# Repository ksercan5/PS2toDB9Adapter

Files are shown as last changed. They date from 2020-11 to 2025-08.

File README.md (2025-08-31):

# PS2toDB9Adapter
Use your Playstation2 Dualshock with Retro Computers (Commodore, Amiga and Atari)

For this project I used Bill Porter's PS2X Arduino Library (http://www.billporter.info/2010/06/05/playstation-2-controller-arduino-library-v1-0/)

For detailed information, please visit (http://seco.gen.tr/2020/07/20/ps2-dualshock-to-c64-joystick-port-mod/)

Use mouse_and_joystick arduino source code to add mouse functionality to your adapter.
To use mouse function (For Amiga only) Press R2 or L2 on Dualshock and move right analog stick. Cross is Left and Square is for Right Mouse Button

For first batch of production (only commodore.gen.tr users), please use v1.1

Other productions use V2 file. (Or you can use the file with mouse support)

# UPDATE:

New double card for C64 will be used to connect two PS2 controllers. Only one Arduino Nano will be enough (Finally tested ok:)

Please download the firmware for double board.

PCBWAY Link: https://www.pcbway.com/project/shareproject/Playstation_PS2_Dualshock_to_DB9__DSUB_9__Adapter_for_Commodore__Amiga_and_Atari_Computers.html

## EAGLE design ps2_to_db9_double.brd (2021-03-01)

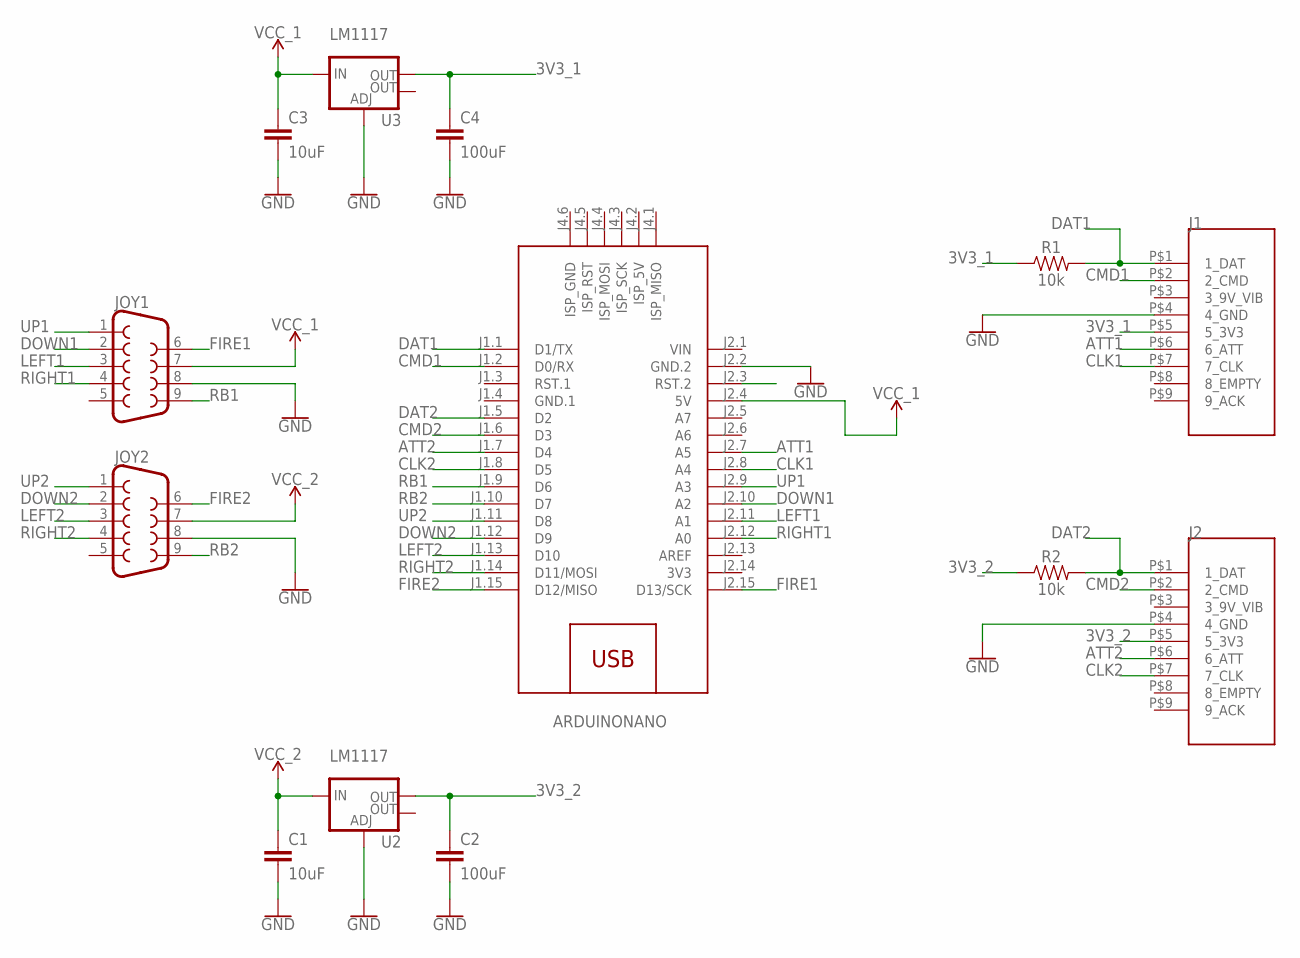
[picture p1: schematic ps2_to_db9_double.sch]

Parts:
ARDUINONANO: ARDUINO-NANO-3.0#ISP
C1, C3: 10uF; C025-025X050
C2, C4: 100uF; C025-025X050
J1, J2: PS2_DUALSHOCK_UP
JOY1, JOY2: DB9FEMALE; DB9
R1, R2: 10k; AXIAL-0.3
U2, U3: LM1117; SOT223

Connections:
3V3: ARDUINONANO.J2.14 (3V3)
3V3_1: C4.1, J1.P$5 (5_3V3), R1.P$1 (1), U3.2 (OUT)
3V3_2: C2.1, J2.P$5 (5_3V3), R2.P$1 (1), U2.2 (OUT)
ATT1: ARDUINONANO.J2.7 (A5), J1.P$6 (6_ATT)
ATT2: ARDUINONANO.J1.7 (D4), J2.P$6 (6_ATT)
CLK1: ARDUINONANO.J2.8 (A4), J1.P$7 (7_CLK)
CLK2: ARDUINONANO.J1.8 (D5), J2.P$7 (7_CLK)
CMD1: ARDUINONANO.J1.2 (D0/RX), J1.P$2 (2_CMD)
CMD2: ARDUINONANO.J1.6 (D3), J2.P$2 (2_CMD)
DAT1: ARDUINONANO.J1.1 (D1/TX), J1.P$1 (1_DAT), R1.P$2 (2)
DAT2: ARDUINONANO.J1.5 (D2), J2.P$1 (1_DAT), R2.P$2 (2)
DOWN1: ARDUINONANO.J2.10 (A2), JOY1.2
DOWN2: ARDUINONANO.J1.12 (D9), JOY2.2
FIRE1: ARDUINONANO.J2.15 (D13/SCK), JOY1.6
FIRE2: ARDUINONANO.J1.15 (D12/MISO), JOY2.6
GND: ARDUINONANO.J2.2 (GND.2), C1.2, C2.2, C3.2, C4.2, J1.P$4 (4_GND), J2.P$4 (4_GND), JOY1.8, JOY2.8, U2.1 (ADJ), U3.1 (ADJ)
GND.1: ARDUINONANO.J1.4 (GND.1)
LEFT1: ARDUINONANO.J2.11 (A1), JOY1.3
LEFT2: ARDUINONANO.J1.13 (D10), JOY2.3
RB1: ARDUINONANO.J1.9 (D6), JOY1.9
RB2: ARDUINONANO.J1.10 (D7), JOY2.9
RIGHT1: ARDUINONANO.J2.12 (A0), JOY1.4
RIGHT2: ARDUINONANO.J1.14 (D11/MOSI), JOY2.4
UP1: ARDUINONANO.J2.9 (A3), JOY1.1
UP2: ARDUINONANO.J1.11 (D8), JOY2.1
VCC_1: ARDUINONANO.J2.4 (5V), C3.1, JOY1.7, U3.3 (IN)
VCC_2: C1.1, JOY2.7, U2.3 (IN)
VIN: ARDUINONANO.J2.1 (VIN)

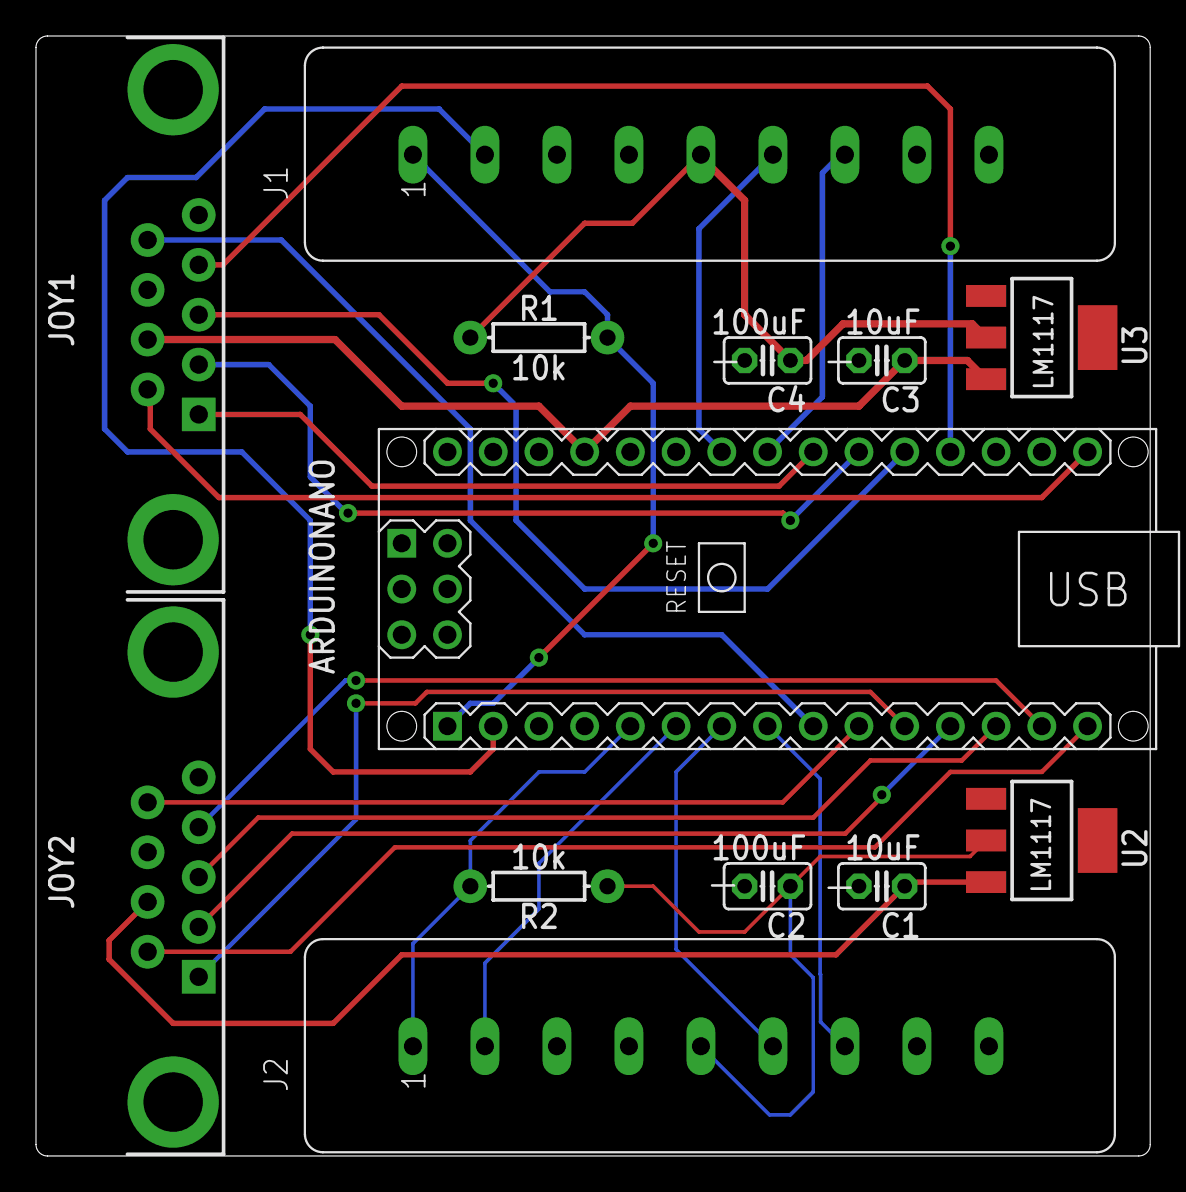
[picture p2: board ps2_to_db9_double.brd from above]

Board: 2 copper layers, 61.9 x 62.2 mm, 13 parts (0 on the bottom side), 25 nets.

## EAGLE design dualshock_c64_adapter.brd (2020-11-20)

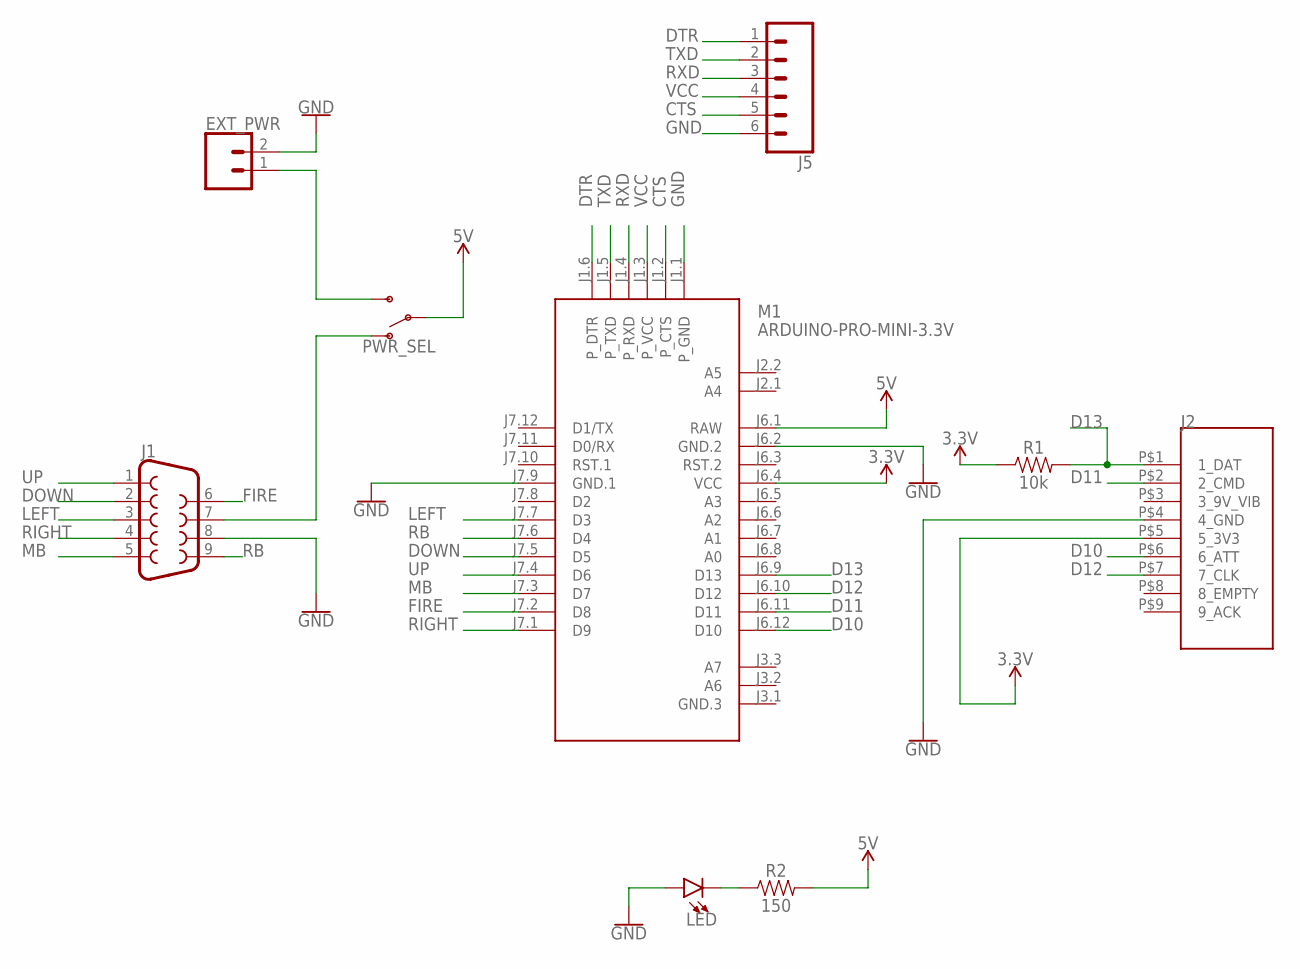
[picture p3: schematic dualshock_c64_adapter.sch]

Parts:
EXT_PWR: CONN_02; 1X02
J1: DB9FEMALE; DB9
J2: PS2_DUALSHOCK
J5: CONN_06NO_SILK_FEMALE_PTH; 1X06_NO_SILK
LED: LED5MM; LED_5MM
M1: ARDUINO-PRO-MINI-3.3V; ARDUINO-PRO-MINI
PWR_SEL: SWITCH-SPDT-PTH-11.6X4.0MM; SWITCH_SPDT_PTH_11.6X4.0MM
R1: 10k; AXIAL-0.3
R2: 150; AXIAL-0.3

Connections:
3.3V: J2.P$5 (5_3V3), M1.J6.4 (VCC), R1.P$1 (1)
5V: M1.J6.1 (RAW), PWR_SEL.2, R2.P$2 (2)
CTS: J5.5, M1.J1.2 (P_CTS)
D10: J2.P$6 (6_ATT), M1.J6.12 (D10)
D11: J2.P$2 (2_CMD), M1.J6.11 (D11)
D12: J2.P$7 (7_CLK), M1.J6.10 (D12)
D13: J2.P$1 (1_DAT), M1.J6.9 (D13), R1.P$2 (2)
DOWN: J1.2, M1.J7.5 (D5)
DTR: J5.1, M1.J1.6 (P_DTR)
FIRE: J1.6, M1.J7.2 (D8)
GND: EXT_PWR.2, J1.8, J2.P$4 (4_GND), J5.6, LED.A, M1.J1.1 (P_GND), M1.J6.2 (GND.2), M1.J7.9 (GND.1)
LEFT: J1.3, M1.J7.7 (D3)
MB: J1.5, M1.J7.3 (D7)
unnamed: LED.K (C), R2.P$1 (1)
unnamed: J1.7, PWR_SEL.1 (O)
unnamed: EXT_PWR.1, PWR_SEL.3 (S)
RB: J1.9, M1.J7.6 (D4)
RIGHT: J1.4, M1.J7.1 (D9)
RXD: J5.3, M1.J1.4 (P_RXD)
TXD: J5.2, M1.J1.5 (P_TXD)
UP: J1.1, M1.J7.4 (D6)
VCC: J5.4, M1.J1.3 (P_VCC)

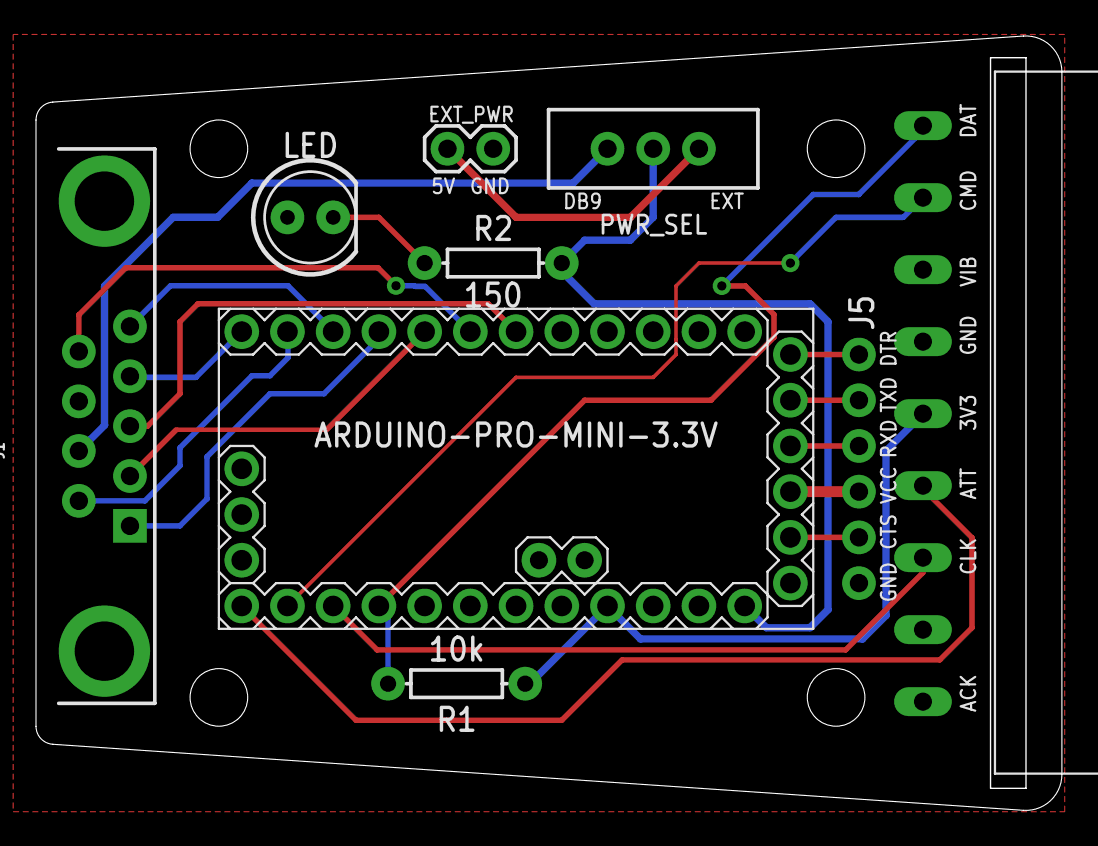
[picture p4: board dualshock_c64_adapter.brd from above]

Board: 2 copper layers, 57.0 x 43.0 mm, 9 parts (0 on the bottom side), 22 nets.

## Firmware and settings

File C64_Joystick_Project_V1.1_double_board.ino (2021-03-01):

// Version Update
// 1.0 Based on Code 2.1 for single adapter
// 27.02.2021
//
// Double Board for C64 with Arduino Nano
// by Sercan Kocabaş


#include <PS2X_lib.h>  //for v1.6

/******************************************************************
 * set pins connected to PS2 controller:
 *   - 1e column: original 
 *   - 2e colmun: Stef?
 * replace pin numbers by the ones you use
 ******************************************************************/
#define PS2_DAT_2        2  //14    
#define PS2_CMD_2        3  //15
#define PS2_SEL_2        4  //16
#define PS2_CLK_2        5  //17

#define C64_UP_2         8
#define C64_DOWN_2       9
#define C64_LEFT_2       10
#define C64_RIGHT_2      11
#define C64_FIRE_2       12

#define PS2_DAT_1        1  //14    
#define PS2_CMD_1        0  //15
#define PS2_SEL_1        A5  //16
#define PS2_CLK_1        A4  //17

#define C64_UP_1         A3
#define C64_DOWN_1       A2
#define C64_LEFT_1       A1
#define C64_RIGHT_1      A0
#define C64_FIRE_1       13

/******************************************************************
 * select modes of PS2 controller:
 *   - pressures = analog reading of push-butttons 
 *   - rumble    = motor rumbling
 * uncomment 1 of the lines for each mode selection
 ******************************************************************/
//#define pressures   true
#define pressures   false
//#define rumble      true
#define rumble      false

PS2X ps2x_1; // create PS2 Controller Class for Joy1
PS2X ps2x_2; // create PS2 Controller Class for Joy2


//right now, the library does NOT support hot pluggable controllers, meaning 
//you must always either restart your Arduino after you connect the controller, 
//or call config_gamepad(pins) again after connecting the controller.

byte error_1 = 0;
byte vibrate_1 = 0;

byte error_2 = 0;
byte vibrate_2 = 0;

void setup(){


  pinMode(A6, INPUT);
  pinMode(A7, INPUT);
  pinMode(C64_FIRE_1, INPUT);
  pinMode(C64_UP_1, INPUT);
  pinMode(C64_DOWN_1, INPUT);
  pinMode(C64_RIGHT_1, INPUT);
  pinMode(C64_LEFT_1, INPUT);


  pinMode(C64_FIRE_2, INPUT);
  pinMode(C64_UP_2, INPUT);
  pinMode(C64_DOWN_2, INPUT);
  pinMode(C64_RIGHT_2, INPUT);
  pinMode(C64_LEFT_2, INPUT);
   
  
  
  //Serial.begin(57600); //Enable this to enable serial communication for troubleshooting, in this case JOY1 will not be available. 
  
  delay(300);  //added delay to give wireless ps2 module some time to startup, before configuring it
   
  //CHANGES for v1.6 HERE!!! **************PAY ATTENTION*************

  Serial.println("Dualshock2 to DB9 (Commodore 64 --- Double Board ---) Adapter Software Ver 1.0");
  
  //setup pins and settings: GamePad(clock, command, attention, data, Pressures?, Rumble?) check for error
  error_1 = ps2x_1.config_gamepad(PS2_CLK_1, PS2_CMD_1, PS2_SEL_1, PS2_DAT_1, pressures, rumble);
  
//  if(error_1 == 0){
//    Serial.print("Found Controller 1, configured successful ");
//    Serial.print("pressures = ");
//	if (pressures)
//	  Serial.println("true ");
//	else
//	  Serial.println("false");
//	Serial.print("rumble = ");
//	if (rumble)
//	  Serial.println("true)");
//	else
//	  Serial.println("false");
//    Serial.println("Note: Go to https://github.com/ksercan5/PS2toDB9Adapter for updates and to report bugs.");
//  }  
//  else if(error_1 == 1)
//    Serial.println("No controller 1 found, check wiring, see readme.txt to enable debug. visit www.billporter.info for troubleshooting tips");
//   
//  else if(error_1 == 2)
//    Serial.println("Controller 1 found but not accepting commands. see readme.txt to enable debug. Visit www.billporter.info for troubleshooting tips");
//
//  else if(error_1 == 3)
//    Serial.println("Controller 1 refusing to enter Pressures mode, may not support it. ");
  
error_2 = ps2x_2.config_gamepad(PS2_CLK_2, PS2_CMD_2, PS2_SEL_2, PS2_DAT_2, pressures, rumble);
  
//  if(error_2 == 0){
//    Serial.print("Found Controller 2, configured successful ");
//    Serial.print("pressures = ");
//  if (pressures)
//    Serial.println("true ");
//  else
//    Serial.println("false");
//  Serial.print("rumble = ");
//  if (rumble)
//    Serial.println("true)");
//  else
//    Serial.println("false");
//    Serial.println("Note: Go to https://github.com/ksercan5/PS2toDB9Adapter for updates and to report bugs.");
//  }  
//  else if(error_2 == 1)
//    Serial.println("No controller 2 found, check wiring, see readme.txt to enable debug. visit www.billporter.info for troubleshooting tips");
//   
//  else if(error_2 == 2)
//    Serial.println("Controller 2 found but not accepting commands. see readme.txt to enable debug. Visit www.billporter.info for troubleshooting tips");
//
//  else if(error_2 == 3)
//    Serial.println("Controller 2 refusing to enter Pressures mode, may not support it. ");
//  
//
}


void check_joy1() {
  ps2x_1.read_gamepad(false, vibrate_1);
  // Analog left for Joy 1
    if(ps2x_1.Analog(PSS_LY) < 30 ){
      pinMode(C64_UP_1, OUTPUT);
      digitalWrite(C64_UP_1, LOW);
//      Serial.println("Analog up");
      }  else if ((!ps2x_1.Button(PSB_CIRCLE))&&(!ps2x_1.Button(PSB_PAD_UP)))
      pinMode(C64_UP_1, INPUT);
  
    if(ps2x_1.Analog(PSS_LY) > 225 ){
      pinMode(C64_DOWN_1, OUTPUT);
      digitalWrite(C64_DOWN_1, LOW);
//      Serial.println("Analog down");
      }  else if (!ps2x_1.Button(PSB_PAD_DOWN))
      pinMode(C64_DOWN_1, INPUT);
    
    if(ps2x_1.Analog(PSS_LX) < 20 ){
      pinMode(C64_LEFT_1, OUTPUT);
      digitalWrite(C64_LEFT_1, LOW);
//      Serial.println("Analog left");
      }  else if (!ps2x_1.Button(PSB_PAD_LEFT))
      pinMode(C64_LEFT_1, INPUT);
      
    if(ps2x_1.Analog(PSS_LX) > 235 ){
      pinMode(C64_RIGHT_1, OUTPUT);
      digitalWrite(C64_RIGHT_1, LOW);
//      Serial.println("Analog right");
      }  else if (!ps2x_1.Button(PSB_PAD_RIGHT))
      pinMode(C64_RIGHT_1, INPUT);

    if(ps2x_1.ButtonPressed(PSB_CIRCLE)) {              //will be TRUE if button was JUST pressed
//      Serial.println("Circle just pressed");
      pinMode(C64_UP_1, OUTPUT);
      digitalWrite(C64_UP_1, LOW);
    }  
     if(ps2x_1.ButtonPressed(PSB_CROSS)) {              //will be TRUE if button was JUST pressed
//      Serial.println("Cross just pressed");
      pinMode(C64_FIRE_1, OUTPUT);
      digitalWrite(C64_FIRE_1, LOW);
    }  
    if(ps2x_1.Button(PSB_TRIANGLE)) {              //Autofire code
//      Serial.println("Autofire pressed (Square)");
      pinMode(C64_FIRE_1, OUTPUT);
      digitalWrite(C64_FIRE_1, LOW);
      delay(50);
      pinMode(C64_FIRE_1, INPUT);
    }  
    
    if (ps2x_1.ButtonPressed(PSB_PAD_UP)) {
//      Serial.println("Pad Up pressed");
      pinMode(C64_UP_1, OUTPUT);
      digitalWrite(C64_UP_1, LOW);
    }    
    if (ps2x_1.ButtonPressed(PSB_PAD_DOWN)) {
//      Serial.println("Pad Down pressed");
      pinMode(C64_DOWN_1, OUTPUT);
      digitalWrite(C64_DOWN_1, LOW);
    }
      if (ps2x_1.ButtonPressed(PSB_PAD_LEFT)) {
//      Serial.println("Pad Left pressed");
      pinMode(C64_LEFT_1, OUTPUT);
      digitalWrite(C64_LEFT_1, LOW);
    }

    if (ps2x_1.ButtonPressed(PSB_PAD_RIGHT)) {
//      Serial.println("Pad Right pressed");
      pinMode(C64_RIGHT_1, OUTPUT);
      digitalWrite(C64_RIGHT_1, LOW);
    }   

    //Button released part Joy 1
 
    if(ps2x_1.ButtonReleased(PSB_CIRCLE)) {             //will be TRUE if button was JUST released
//      Serial.println("Circle just released");     
      pinMode(C64_UP_1, INPUT);
    }

    if(ps2x_1.ButtonReleased(PSB_CROSS)) {             //will be TRUE if button was JUST released
//      Serial.println("Cross just released");     
      pinMode(C64_FIRE_1, INPUT);
    }

    if(ps2x_1.ButtonReleased(PSB_TRIANGLE)) {             //will be TRUE if button was JUST released
//      Serial.println("Square just released");     
      pinMode(C64_FIRE_1, INPUT);
    }
    
    if (ps2x_1.ButtonReleased(PSB_PAD_UP)) {
//      Serial.println("Pad Up Released");
      pinMode(C64_UP_1, INPUT);
    }    

    if (ps2x_1.ButtonReleased(PSB_PAD_DOWN)) {
//      Serial.println("Pad Down Released");
      pinMode(C64_DOWN_1, INPUT);
    }    
    
    if (ps2x_1.ButtonReleased(PSB_PAD_LEFT)) {
//      Serial.println("Pad Left Released");
      pinMode(C64_LEFT_1, INPUT);
    }    
    
    if (ps2x_1.ButtonReleased(PSB_PAD_RIGHT)) {
//      Serial.println("Pad Rıght Released");
      pinMode(C64_RIGHT_1, INPUT);
    }  
}


void check_joy2() {
  ps2x_2.read_gamepad(false, vibrate_2);
// Analog left for Joy 2

    if(ps2x_2.Analog(PSS_LY) < 30 ){
      pinMode(C64_UP_2, OUTPUT);
      digitalWrite(C64_UP_2, LOW);
//      Serial.println("Analog up");
      }  else if ((!ps2x_2.Button(PSB_CIRCLE))&&(!ps2x_2.Button(PSB_PAD_UP)))
      pinMode(C64_UP_2, INPUT);
  
    if(ps2x_2.Analog(PSS_LY) > 225 ){
      pinMode(C64_DOWN_2, OUTPUT);
      digitalWrite(C64_DOWN_2, LOW);
 //     Serial.println("Analog down");
      }  else if (!ps2x_2.Button(PSB_PAD_DOWN))
      pinMode(C64_DOWN_2, INPUT);
    
    if(ps2x_2.Analog(PSS_LX) < 20 ){
      pinMode(C64_LEFT_2, OUTPUT);
      digitalWrite(C64_LEFT_2, LOW);
//      Serial.println("Analog left");
      }  else if (!ps2x_2.Button(PSB_PAD_LEFT))
      pinMode(C64_LEFT_2, INPUT);
      
    if(ps2x_2.Analog(PSS_LX) > 235 ){
      pinMode(C64_RIGHT_2, OUTPUT);
      digitalWrite(C64_RIGHT_2, LOW);
//      Serial.println("Analog right");
      }  else if (!ps2x_2.Button(PSB_PAD_RIGHT))
      pinMode(C64_RIGHT_2, INPUT);

    if(ps2x_2.ButtonPressed(PSB_CIRCLE)) {              //will be TRUE if button was JUST pressed
//      Serial.println("Circle just pressed");
      pinMode(C64_UP_2, OUTPUT);
      digitalWrite(C64_UP_2, LOW);
    }  
    if(ps2x_2.ButtonPressed(PSB_CROSS)) {              //will be TRUE if button was JUST pressed
//      Serial.println("Cross just pressed");
      pinMode(C64_FIRE_2, OUTPUT);
      digitalWrite(C64_FIRE_2, LOW);
    } 

    if(ps2x_2.Button(PSB_TRIANGLE)) {              //Autofire code
//      Serial.println("Autofire pressed (Square)");
      pinMode(C64_FIRE_2, OUTPUT);
      digitalWrite(C64_FIRE_2, LOW);
      delay(50);
      pinMode(C64_FIRE_2, INPUT);
    }  
     if (ps2x_2.ButtonPressed(PSB_PAD_UP)) {
//      Serial.println("Pad Up pressed");
      pinMode(C64_UP_2, OUTPUT);
      digitalWrite(C64_UP_2, LOW);
    }
    if (ps2x_2.ButtonPressed(PSB_PAD_DOWN)) {
//      Serial.println("Pad Down pressed");
      pinMode(C64_DOWN_2, OUTPUT);
      digitalWrite(C64_DOWN_2, LOW);
    }
    if (ps2x_2.ButtonPressed(PSB_PAD_LEFT)) {
//      Serial.println("Pad Left pressed");
      pinMode(C64_LEFT_2, OUTPUT);
      digitalWrite(C64_LEFT_2, LOW);
    }
    if (ps2x_2.ButtonPressed(PSB_PAD_RIGHT)) {
//      Serial.println("Pad Right pressed");
      pinMode(C64_RIGHT_2, OUTPUT);
      digitalWrite(C64_RIGHT_2, LOW);
    }   

     //Button released part Joy 2

    if(ps2x_2.ButtonReleased(PSB_CIRCLE)) {             //will be TRUE if button was JUST released
//      Serial.println("Circle just released");     
      pinMode(C64_UP_2, INPUT);
    }

    if(ps2x_2.ButtonReleased(PSB_CROSS)) {             //will be TRUE if button was JUST released
//      Serial.println("Cross just released");     
      pinMode(C64_FIRE_2, INPUT);
    }

    if(ps2x_2.ButtonReleased(PSB_TRIANGLE)) {             //will be TRUE if button was JUST released
//      Serial.println("Square just released");     
      pinMode(C64_FIRE_2, INPUT);
    }
    
    if (ps2x_2.ButtonReleased(PSB_PAD_UP)) {
//      Serial.println("Pad Up Released");
      pinMode(C64_UP_2, INPUT);
    }    

    if (ps2x_2.ButtonReleased(PSB_PAD_DOWN)) {
//      Serial.println("Pad Down Released");
      pinMode(C64_DOWN_2, INPUT);
    }    
    
    if (ps2x_2.ButtonReleased(PSB_PAD_LEFT)) {
//      Serial.println("Pad Left Released");
      pinMode(C64_LEFT_2, INPUT);
    }    
    
    if (ps2x_2.ButtonReleased(PSB_PAD_RIGHT)) {
//      Serial.println("Pad Rıght Released");
      pinMode(C64_RIGHT_2, INPUT);
    }   
}

void loop() {
  if (error_1 == 0) check_joy1();
  if (error_2 == 0) check_joy2();
  delay(25);   //Default 50
}

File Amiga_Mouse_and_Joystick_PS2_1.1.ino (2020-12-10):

#include <PS2X_lib.h>  //for v1.6

/*Data from PS2-Mouse:
 * 
 * data0[2:1:0]  ->  middle,right, left mousebutton
 * data1         ->  x from -127 to + 127   signed int
 * data2         ->  y from -127 to + 127   signed int
 * 
 * 
 * amiga mouse-port, looking at the amiga:
 * 
 * 9 PIN D-SUB MALE
 * 
 *   _________________________
 *   \                       /
 *    \  1   2   3   4   5  /
 *     \                   /
 *      \  6   7   8   9  /
 *       \_______________/
 * 
 * 1  V-pulse               
 * 2  H-pulse
 * 3  VQ-pulse
 * 4  HQ-pulse
 * 5  BUTTON 3 (Middle)
 * 6  BUTTON 1 (Lefl)
 * 7  +5V
 * 8  GND
 * 9  BUTTON 2 (Right)
 */

/******************************************************************
 * set pins connected to PS2 controller:
 *   - 1e column: original 
 *   - 2e colmun: Stef?
 * replace pin numbers by the ones you use
 ******************************************************************/
#define PS2_DAT        13  //14    
#define PS2_CMD        11  //15
#define PS2_SEL        10  //16
#define PS2_CLK        12  //17

/*                  ARDUINO PIN SETUP                             */
/*                  Joy Pins | Mouse Pins                         */

#define C64_UP         6     //   V-Pulse
#define C64_DOWN       5     //   H-Pulse
#define C64_LEFT       3     //   VQ-Pulse
#define C64_RIGHT      9     //   HQ-Pulse
#define C64_FIRE       8     //   LMB
#define RMB            4     //   RMB
#define MB             7     //   MB

#define ADELAY         200
/******************************************************************
 * select modes of PS2 controller:
 *   - pressures = analog reading of push-butttons 
 *   - rumble    = motor rumbling
 * uncomment 1 of the lines for each mode selection
 ******************************************************************/
//#define pressures   true
#define pressures   false
//#define rumble      true
#define rumble      false

PS2X ps2x; // create PS2 Controller Class

//right now, the library does NOT support hot pluggable controllers, meaning 
//you must always either restart your Arduino after you connect the controller, 
//or call config_gamepad(pins) again after connecting the controller.

int error = 0;
byte type = 0;
byte vibrate = 0;

// quadrature encoding used by the amiga mouse protocol***
//
uint8_t H[4]  = { LOW, LOW, HIGH, HIGH};
uint8_t HQ[4] = { LOW, HIGH, HIGH, LOW};

uint8_t QX = 3;
uint8_t QY = 3;

uint8_t XSTEPS;
uint8_t YSTEPS;
uint8_t XSIGN;
uint8_t YSIGN;
int X;
int Y;
/*********************************************************/

const byte ANALOG_IDLE_VALUE = 128;


// x/y handling*******************************************
//
void AMIGAHorizontalMove() {
    pinMode(C64_DOWN, OUTPUT);
    pinMode(C64_RIGHT, OUTPUT);
    // set bits acc. to curr. position in quadr. sequence
    digitalWrite(C64_DOWN, H[QX]);
    delayMicroseconds(ADELAY);
    digitalWrite(C64_RIGHT, HQ[QX]);
//    pinMode(C64_DOWN, INPUT);
//    pinMode(C64_RIGHT, INPUT);
}


void AMIGAVerticalMove() {
    pinMode(C64_UP, OUTPUT);
    pinMode(C64_LEFT, OUTPUT);
    digitalWrite(C64_UP, H[QY]);
    delayMicroseconds(ADELAY);
    digitalWrite(C64_LEFT, HQ[QY]);
//    pinMode(C64_UP, INPUT);
//    pinMode(C64_LEFT, INPUT);
}


void AMIGA_Left() {
    
    // do a move by setting the port
    AMIGAHorizontalMove();

    // advance in the quadr. sequence
    QX = (QX >= 3) ? 0 : ++QX;
    
}

void AMIGA_Right() {
    AMIGAHorizontalMove();
    QX = (QX <= 0) ? 3 : --QX;
}

void AMIGA_Down() {
    AMIGAVerticalMove();
    QY = QY <= 0 ? 3 : --QY;
}

void AMIGA_Up() {
    AMIGAVerticalMove();
    QY = QY >= 3 ? 0 : ++QY;
}

/****************************************************************************/

void setup(){
 
  pinMode(C64_FIRE, INPUT);
  pinMode(C64_UP, INPUT);
  pinMode(C64_DOWN, INPUT);
  pinMode(C64_RIGHT, INPUT);
  pinMode(C64_LEFT, INPUT);
  pinMode(RMB, INPUT); 
  pinMode(MB, INPUT);
  Serial.begin(57600);
  
  delay(300);  //added delay to give wireless ps2 module some time to startup, before configuring it
   
  //CHANGES for v1.6 HERE!!! **************PAY ATTENTION*************

  Serial.println("Dualshock2 to DB9 (Commodore, Amiga, Atari) Adapter Software Ver 1.1 (With Mouse Mode)");
  
  //setup pins and settings: GamePad(clock, command, attention, data, Pressures?, Rumble?) check for error
  error = ps2x.config_gamepad(PS2_CLK, PS2_CMD, PS2_SEL, PS2_DAT, pressures, rumble);
  
  if(error == 0){
    Serial.print("Found Controller, configured successful ");
    Serial.print("pressures = ");
	if (pressures)
	  Serial.println("true ");
	else
	  Serial.println("false");
	Serial.print("rumble = ");
	if (rumble)
	  Serial.println("true)");
	else
	  Serial.println("false");
    Serial.println("Try out all the buttons, X will vibrate the controller, faster as you press harder;");
    Serial.println("holding L1 or R1 will print out the analog stick values.");
    Serial.println("Note: Go to www.billporter.info for updates and to report bugs.");
  }  
  else if(error == 1)
    Serial.println("No controller found, check wiring, see readme.txt to enable debug. visit www.billporter.info for troubleshooting tips");
   
  else if(error == 2)
    Serial.println("Controller found but not accepting commands. see readme.txt to enable debug. Visit www.billporter.info for troubleshooting tips");

  else if(error == 3)
    Serial.println("Controller refusing to enter Pressures mode, may not support it. ");
  
//  Serial.print(ps2x.Analog(1), HEX);
  
  type = ps2x.readType(); 
  switch(type) {
    case 0:
      Serial.print("Unknown Controller type found ");
      break;
    case 1:
      Serial.print("DualShock Controller found ");
      break;
    case 2:
      Serial.print("GuitarHero Controller found ");
      break;
	case 3:
      Serial.print("Wireless Sony DualShock Controller found ");
      break;
   }
}
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

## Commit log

2020-11-20 Some minor changes on PCB design
    Rerouting and dimension change on pins
    [dualshock_c64_adapter.brd, dualshock_c64_adapter.sch]
2021-01-26 Update in software, 2nd Fire button for Amiga added
2021-03-01 Updated schematics
    [ps2_to_db9_double.brd, ps2_to_db9_double.sch]
2021-08-30 3d cover stl files upload

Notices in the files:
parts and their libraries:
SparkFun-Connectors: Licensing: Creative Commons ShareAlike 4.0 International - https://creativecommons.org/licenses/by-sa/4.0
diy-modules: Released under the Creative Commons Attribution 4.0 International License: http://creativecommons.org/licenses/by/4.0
